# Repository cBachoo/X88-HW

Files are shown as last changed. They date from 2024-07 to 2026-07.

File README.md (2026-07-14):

# X88H - Hybrid USB/JST





## License

This work is licensed under a [Creative Commons Attribution-ShareAlike 4.0 International License](https://creativecommons.org/licenses/by-sa/4.0/).

You are free to produce, modify, manufacture, and distribute this design, including for commercial purposes, provided you give appropriate credit and license any derivative works under the same terms.

Questions? Contact Bachoo (`bachoobusiness[at]gmail.com`).

[][cc-by-sa]

[cc-by-sa]: http://creativecommons.org/licenses/by-sa/4.0/
[cc-by-sa-image]: https://licensebuttons.net/l/by-sa/4.0/88x31.png
[cc-by-sa-shield]: https://img.shields.io/badge/License-CC%20BY--SA%204.0-lightgrey.svg

## Changelog

- 17 Aug 2024
    - Rotated JST connector so it's facing the alphas

## Design Files / Libraries

The files were designed with [KiCAD 8.0.4](https://www.kicad.org/).

The [marbastlib](https://github.com/ebastler/marbastlib) MX switch symbol/footprint library is used for the project.

The 3D model for the PCB can be seen in the main folder under `X88H-3D-model.step`.

## Ordering from JLCPCB

1) Head to the [JLCPCB order page](https://cart.jlcpcb.com/quote).

2) Upload the `GERBER-X88H.zip` file in `jlcpcb/production_files/`.

3) Set the quantity of the PCBs you want made.

4) Set your desired PCB parameters. Here are some suggested parameters: (Everything else can be kept at their default)

- PCB Color: **Black**
- Surface Finish: **ENIG**
- Remove Order Number: **Yes**   

5) Enable the PCB Assembly option at the bottom, and set the following parameters:

- PCBA Type: **Standard**
- Assembly Side: **Both Sides**

6) Press `Confirm` at the bottom or `NEXT` on the right to get to the next page.

7) Click `NEXT` to get to the Bill of Materials tab.

8) Click `Add BOM File` and select the `BOM-X88H.csv` file in `jlcpcb/production_files/`.

9) Click `Add CPL File` and select the `CPL-X88H.csv` file in `jlcpcb/production_files/`. Click `Process BOM & CPL` to proceed.

10) You should be presented with a list of all the components and quantities needed. Double check there are no missing components. If there are, you will have to find substitute components for it. Click `NEXT` to proceed.

11) You should be presented with a view of the PCB and its components. Click `NEXT` to proceed.

12) You should see a breakdown of the price for the PCBs you want to order. Select `Keyboard - HS Code 847330` under `Office Appliance Accessories` for the Product Description.

13) Save to cart, and pay for it!

## Ordering from PCBWay

1) Head to the [PCBWay Quick Order page](https://www.pcbway.com/QuickOrderOnline.aspx)

2) Click the `Add Gerber file` button and add the `X88H.kicad_pcb.zip` file in the main folder. Don't worry about the broken preview.

3) Set the quantity of the PCBs you want made.

4) Set your desired PCB parameters. Here are some suggested parameters: (Everything else can be kept at their default)

- Solder mask: **Black**
- Surface finish: **Immersion gold (ENIG)**
- Remove product no.: **Yes (extra+$1.5)**

5) Enable the Assembly Service option at the bottom, and set the following parameters:

- Assembly side(s): **Both sides**
- Quantity: **as needed; same number as your PCBs?**
- Do you accept alternatives/substitutes made in China? **Yes**

6) Click Save to Cart. You will have to wait for your order to be reviewed before you can pay for it.

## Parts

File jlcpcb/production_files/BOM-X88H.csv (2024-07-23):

Comment | Designator | Footprint | LCSC
100nF | C10,C11,C2,C3,C7,C9 | C_0402_1005Metric | C1525
10uF | CR1 | C_0402_1005Metric | C15525
SM04B-SRSS-TB | J1 | JST_SH_SM04B-SRSS-TB_1x04-1MP_P1.00mm_Horizontal | C160404
USB_C_Receptacle_USB2.0_16P | USB1 | USB_C_Receptacle_HRO_TYPE-C-31-M-12 | C165948
4.7uF | C1,C8 | C_0402_1005Metric | C23733
100k | RR3 | R_0402_1005Metric | C25741
10k | RR2 | R_0402_1005Metric | C25744
33k | RR1 | R_0402_1005Metric | C25779
4k7 | R3 | R_0402_1005Metric | C25900
5k1 | R1,R2 | R_0402_1005Metric | C25905
PRTR5V0U2X | D1 | SOT-143 | C2827688
TS-1187A-B-A-B | SWR1 | SW_SPST_TL3342 | C318884
SK6812MINI-E | RGB1,RGB2 | LED_6028R | C524051
1uF | C4,C5,C6,CR2 | C_0402_1005Metric | C52923
XC6206P332MR | U1 | SOT-23 | C5446
500mA | F1 | Fuse_1206_3216Metric_Pad1.42x1.75mm_HandSolder | C69688
1N4148W | D10,D11,D12,D13,D14,D15,D16,D17,D18,D19,D2,D20,D21,D22,D23,D24,D25,D26,D27,D28,D29,D3,D30,D31,D32,D33,D34,D35,D36,D37,D38,D39,D4,D40,D41,D42,D43,D44,D45,D46,D47,D48,D49,D5,D50,D51,D52,D53,D54,D55,D56,D57,D58,D59,D6,D60,D61,D62,D63,D64,D65,D66,D67,D68,D69,D7,D70,D71,D72,D73,D74,D75,D76,D77,D78,D79,D8,D80,D81,D82,D83,D84,D85,D86,D87,D88,D89,D9,D90,D91,D92 | D_SOD-123 | C81598
STM32F072CBT6 | U2 | LQFP-48_7x7mm_P0.5mm | C81720
2N7002 | QR1 | SOT-23 | C8545

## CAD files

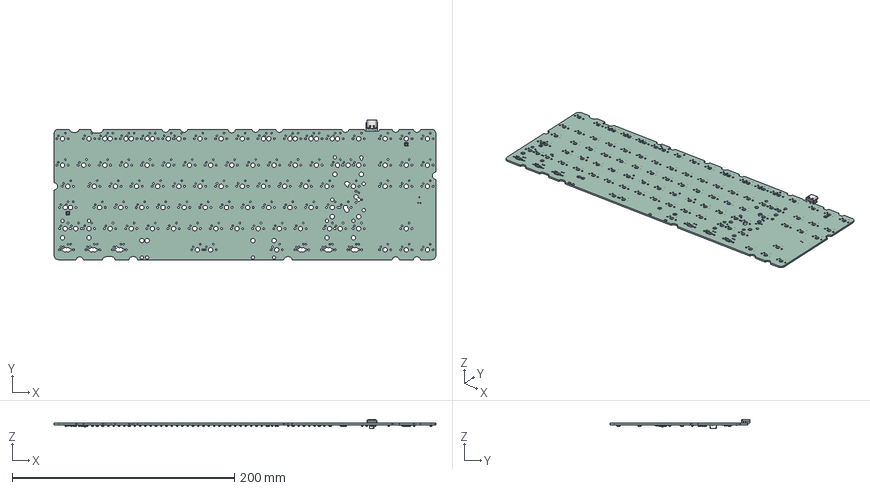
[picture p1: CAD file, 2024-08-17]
X88H-3D-model.step
344.0 x 125.6 x 7.86 mm
CON_TYPE-C-31-M-12 v3
D_SOD_123 x 91
LQFP_48_7x7mm_P05mm
R_0402_1005Metric x 6
C_0402_1005Metric x 13
SW_SPST_TL3342
LED_SK6812MINI-E v2 x 2
SOT_23 x 2
CON_SM04B-SRSS-TB v2
SOT_143
Fuse_1206_3216Metric
X88H_PCB

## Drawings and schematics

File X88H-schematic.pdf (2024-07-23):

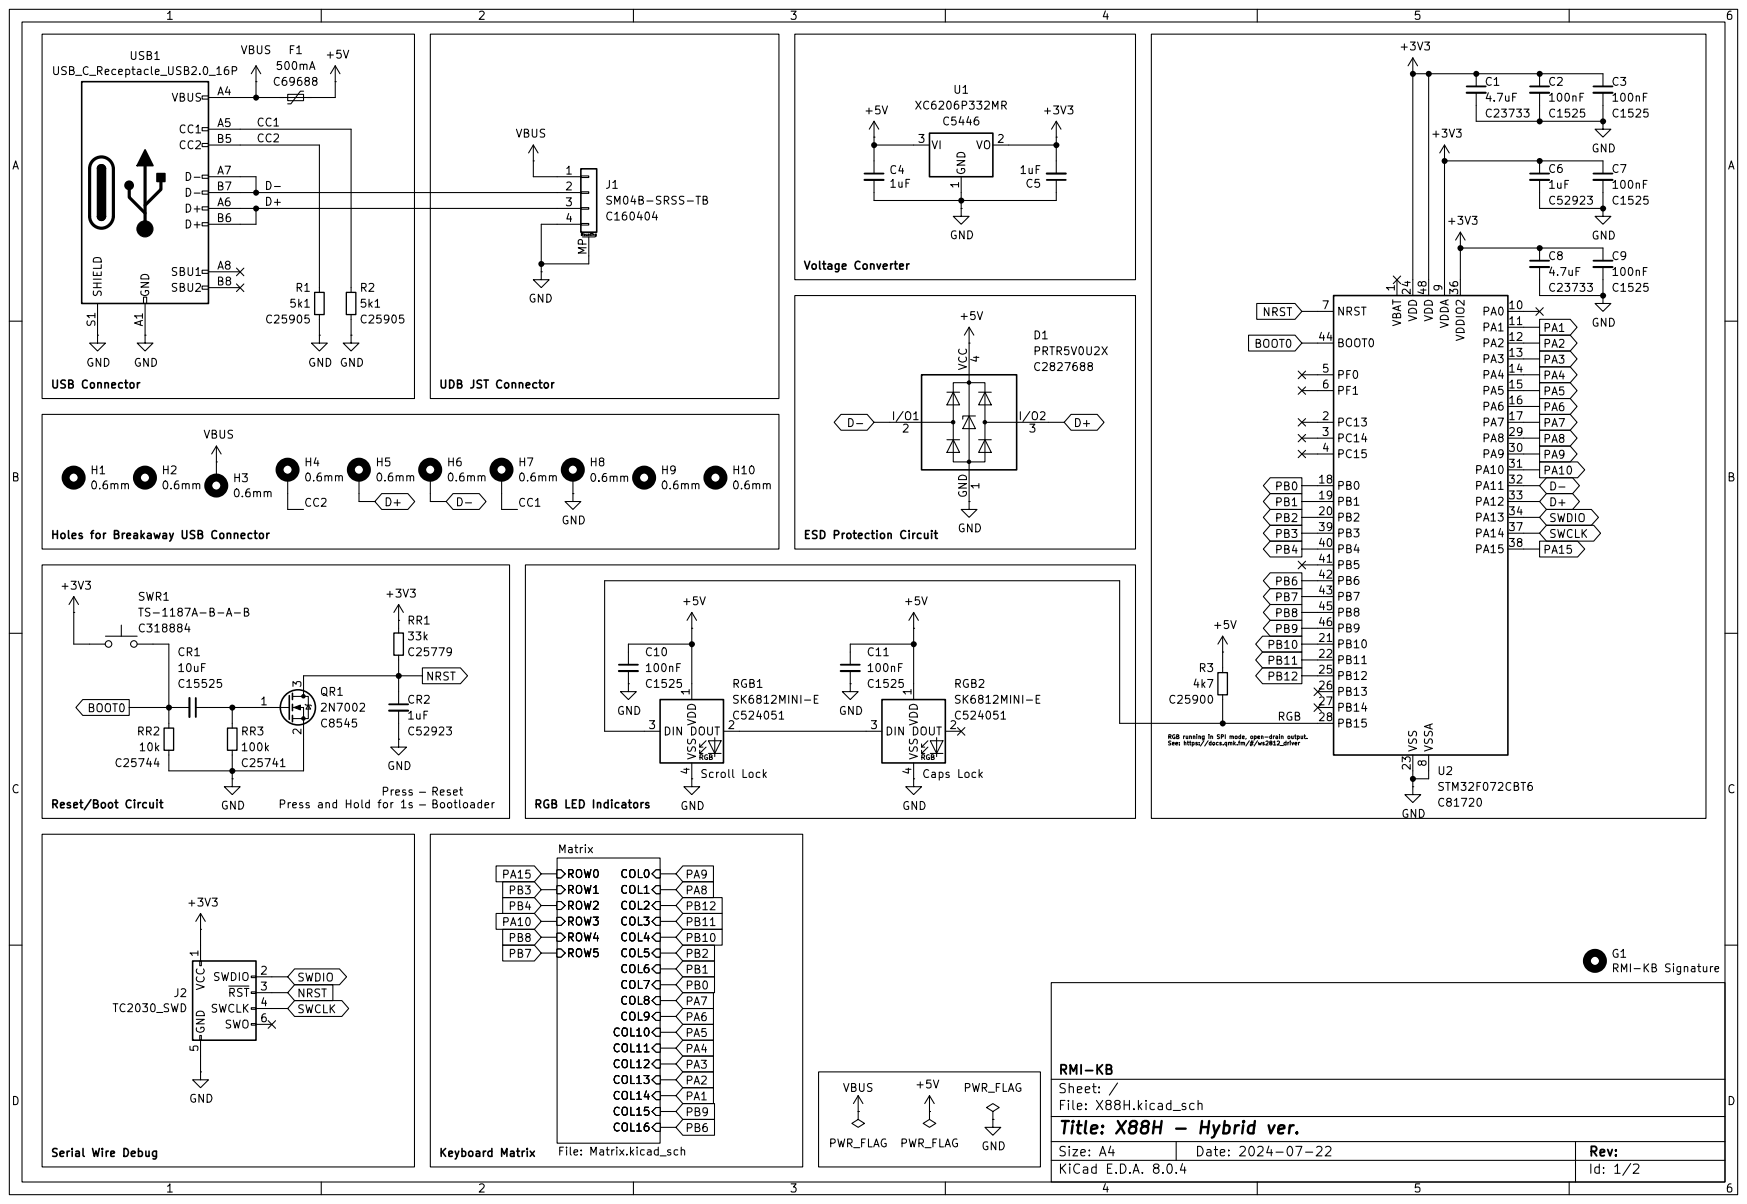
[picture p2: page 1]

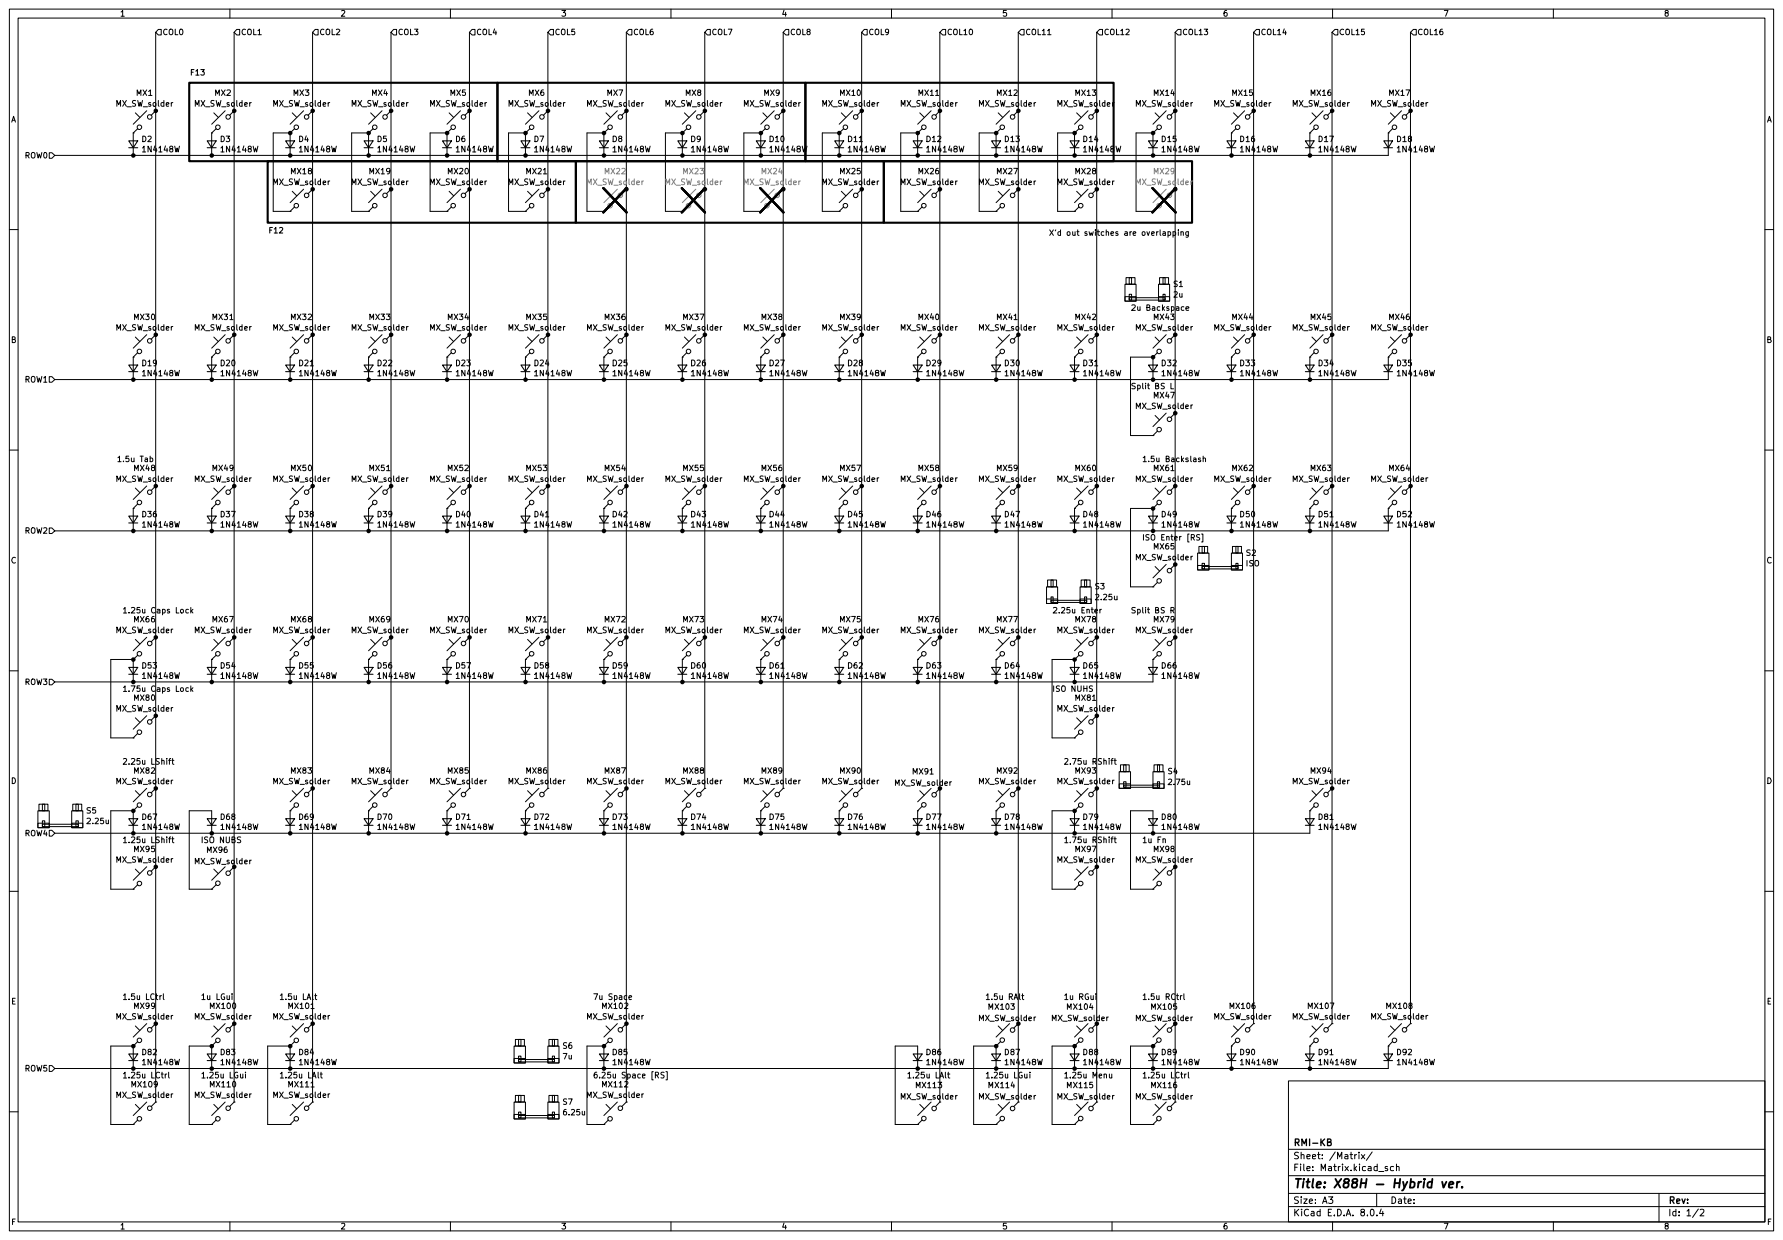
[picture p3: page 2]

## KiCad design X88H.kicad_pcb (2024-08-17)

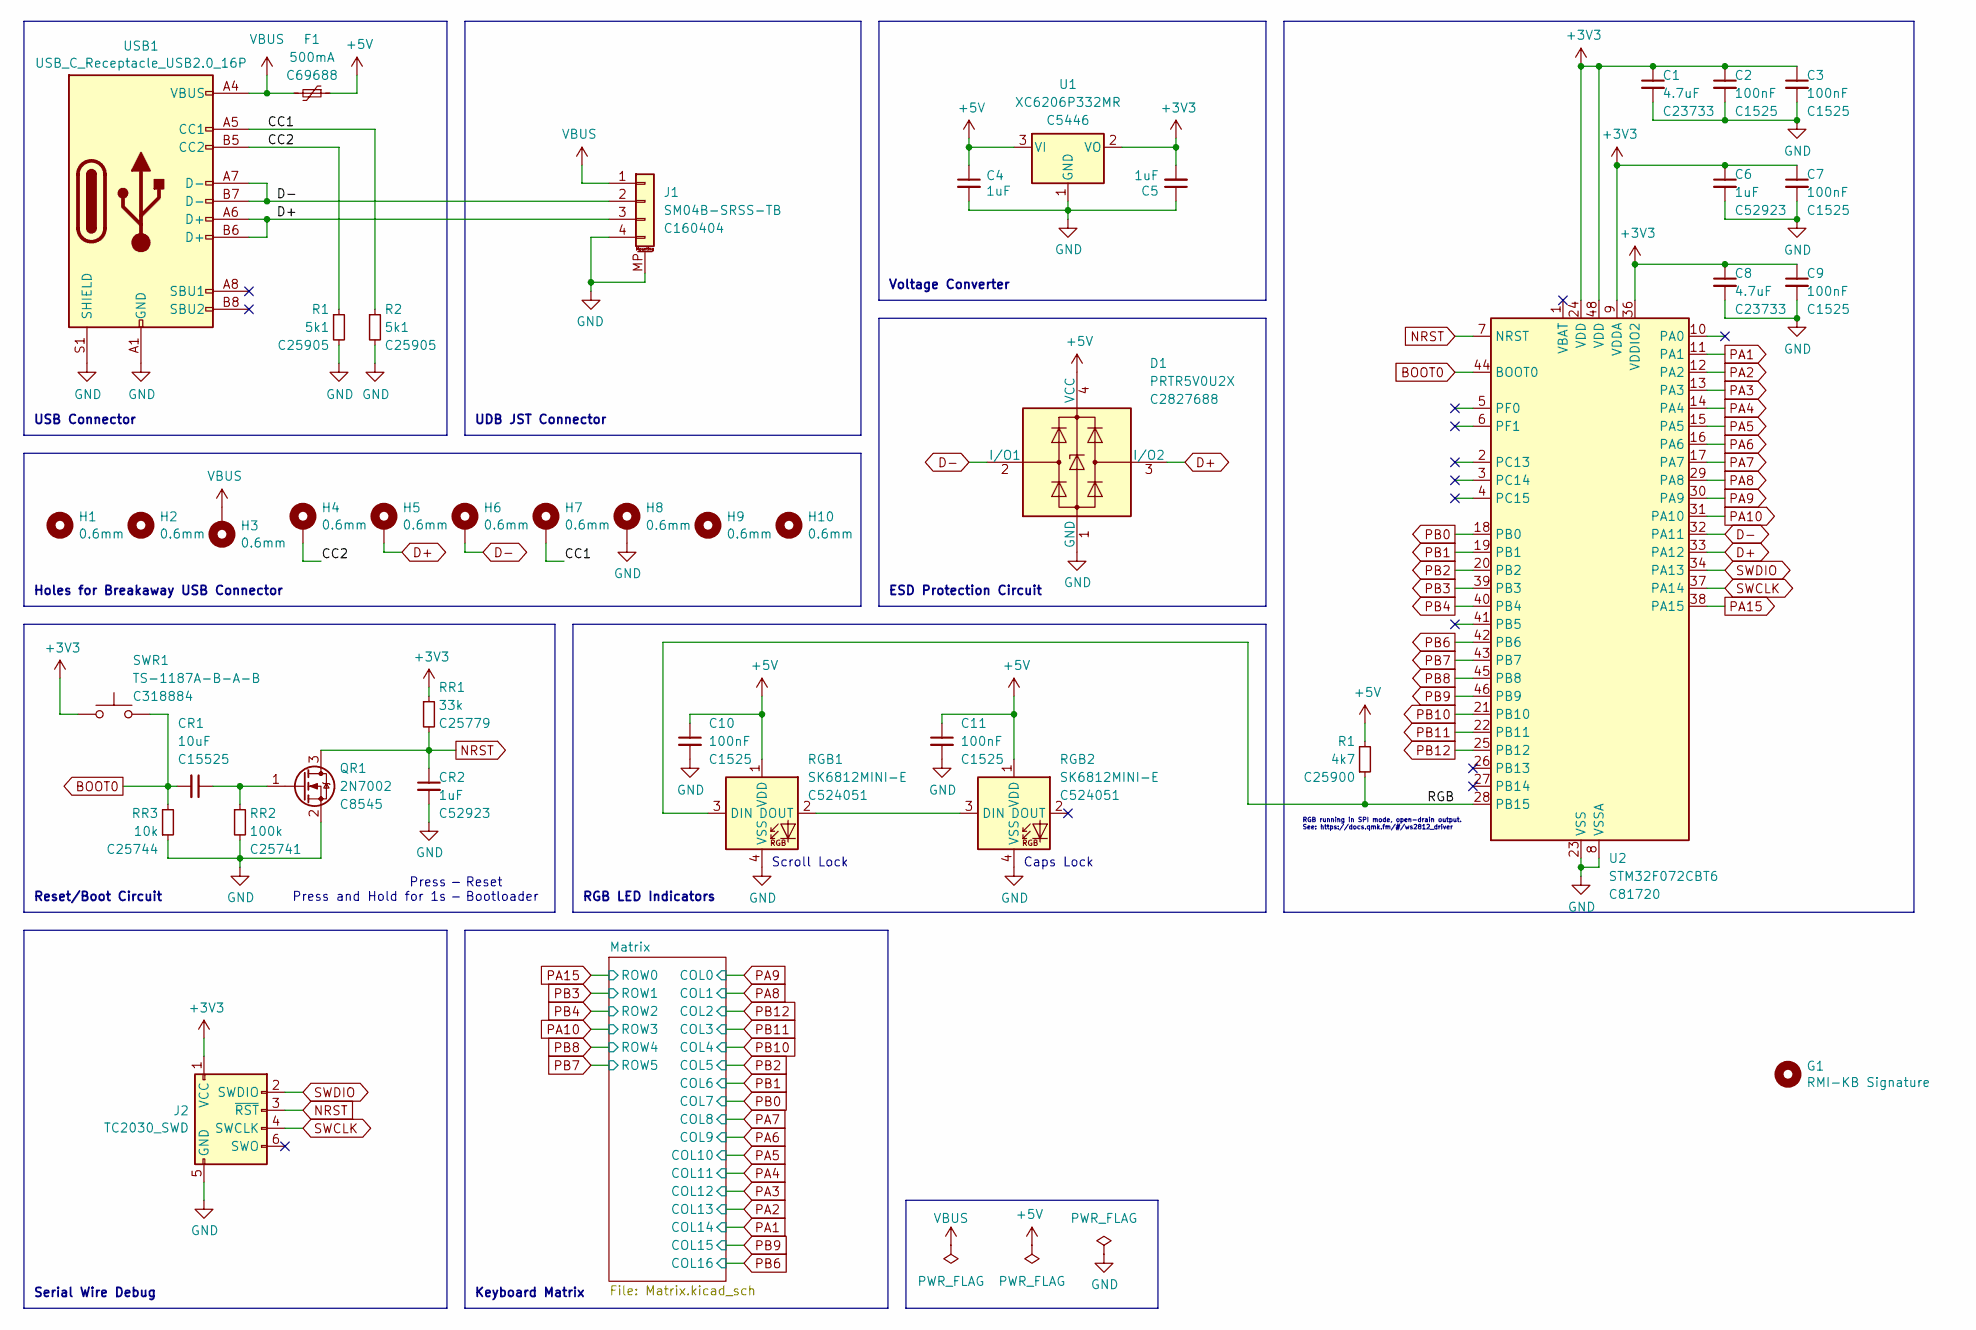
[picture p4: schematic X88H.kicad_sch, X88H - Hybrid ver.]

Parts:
C1, C8: 4.7uF; C_0402_1005Metric; MPN CL05A475MP5NRNC; LCSC C23733
C2, C3, C7, C9, C10, C11: 100nF; C_0402_1005Metric; MPN CL05B104KO5NNNC; LCSC C1525
C4, C5, C6: 1uF; C_0402_1005Metric; MPN CL05A105KA5NQNC; LCSC C52923
CR1: 10uF; C_0402_1005Metric; MPN CL05A106MQ5NUNC; LCSC C15525
CR2: 1uF; C_0402_1005Metric; MPN CL05A105KA5NQNC; LCSC C52923
D1: PRTR5V0U2X; SOT-143; MPN PRTR5V0U2X; LCSC C2827688
F1: 500mA; Fuse_1206_3216Metric_Pad1.42x1.75mm_HandSolder; MPN nSMD050; LCSC C69688
G1: RMI-KB Signature; Signature
H1, H2, H9, H10: 0.6mm; Hole_0.6mm
H3, H4, H5, H6, H7, H8: 0.6mm; Hole_0.6mm_Pad
J1: SM04B-SRSS-TB; JST_SH_SM04B-SRSS-TB_1x04-1MP_P1.00mm_Horizontal; MPN SM04B-SRSS-TB(LF)(SN); LCSC C160404
J2: TC2030_SWD; CON_TC2030_outlined
QR1: 2N7002; SOT-23; MPN 2N7002; LCSC C8545
R1, R2: 5k1; R_0402_1005Metric; MPN 0402WGF5101TCE; LCSC C25905
RGB1, RGB2: SK6812MINI-E; LED_6028R; MPN SK6812MINI-E; LCSC C524051
RR1: 33k; R_0402_1005Metric; MPN 0402WGF3302TCE; LCSC C25779
RR2: 100k; R_0402_1005Metric; MPN 0402WGF1003TCE; LCSC C25741
RR3: 10k; R_0402_1005Metric; MPN 0402WGF1002TCE; LCSC C25744
SWR1: TS-1187A-B-A-B; SW_SPST_TL3342; MPN TS-1187A-B-A-B; LCSC C318884
U1: XC6206P332MR; SOT-23; MPN XC6206P332MR-G; LCSC C5446
U2: STM32F072CBT6; LQFP-48_7x7mm_P0.5mm; MPN STM32F072CBT6; LCSC C81720
USB1: USB_C_Receptacle_USB2.0_16P; USB_C_Receptacle_HRO_TYPE-C-31-M-12; MPN TYPE-C-31-M-12; LCSC C165948

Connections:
+3V3: C1.1, C2.1, C3.1, C5.2, C6.1, C7.1, C8.1, C9.1, J2.1 (VCC), RR1.1, SWR1.1, U1.2 (VO), U2.9 (VDDA), U2.24 (VDD), U2.36 (VDDIO2), U2.48 (VDD)
/CC1: H7.1, R2.1, USB1.A5 (CC1)
D+: D1.3 (I/O2), H5.1, J1.3, U2.33 (PA12), USB1.A6 (D+), USB1.B6 (D+)
D-: D1.2 (I/O1), H6.1, J1.2, U2.32 (PA11), USB1.A7 (D-), USB1.B7 (D-)
NRST: CR2.1, J2.3 (~RST), QR1.3 (D), RR1.2, U2.7 (NRST)
unnamed: RGB1.2 (DOUT), RGB2.3 (DIN)
PA1: U2.11 (PA1); also elsewhere on the board
PA2: U2.12 (PA2); also elsewhere on the board
PA3: U2.13 (PA3); also elsewhere on the board
PA4: U2.14 (PA4); also elsewhere on the board
PA5: U2.15 (PA5); also elsewhere on the board
PA6: U2.16 (PA6); also elsewhere on the board
PA7: U2.17 (PA7); also elsewhere on the board
PA8: U2.29 (PA8); also elsewhere on the board
PA9: U2.30 (PA9); also elsewhere on the board
PA10: U2.31 (PA10); also elsewhere on the board
PA15: U2.38 (PA15); also elsewhere on the board
PB0: U2.18 (PB0); also elsewhere on the board
PB1: U2.19 (PB1); also elsewhere on the board
PB2: U2.20 (PB2); also elsewhere on the board
PB3: U2.39 (PB3); also elsewhere on the board
PB4: U2.40 (PB4); also elsewhere on the board
PB6: U2.42 (PB6); also elsewhere on the board
PB7: U2.43 (PB7); also elsewhere on the board
PB8: U2.45 (PB8); also elsewhere on the board
PB9: U2.46 (PB9); also elsewhere on the board
PB10: U2.21 (PB10); also elsewhere on the board
PB11: U2.22 (PB11); also elsewhere on the board
PB12: U2.25 (PB12); also elsewhere on the board
SWCLK: J2.4 (SWCLK), U2.37 (PA14)
SWDIO: J2.2 (SWDIO), U2.34 (PA13)
VBUS: F1.2, H3.1, J1.1, USB1.A4 (VBUS), USB1.A9 (VBUS), USB1.B4 (VBUS), USB1.B9 (VBUS)

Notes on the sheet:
Holes for Breakaway USB Connector
Reset Bootloader
ESD Protection Circuit
Caps Lock
RGB running in SPI mode, open-drain output. See: https://docs.qmk.fm/#/ws2812_driver
- -
UDB JST Connector
RGB LED Indicators
Voltage Converter
Press Press and Hold for 1s
Reset/Boot Circuit
Serial Wire Debug
Keyboard Matrix
USB Connector
Scroll Lock

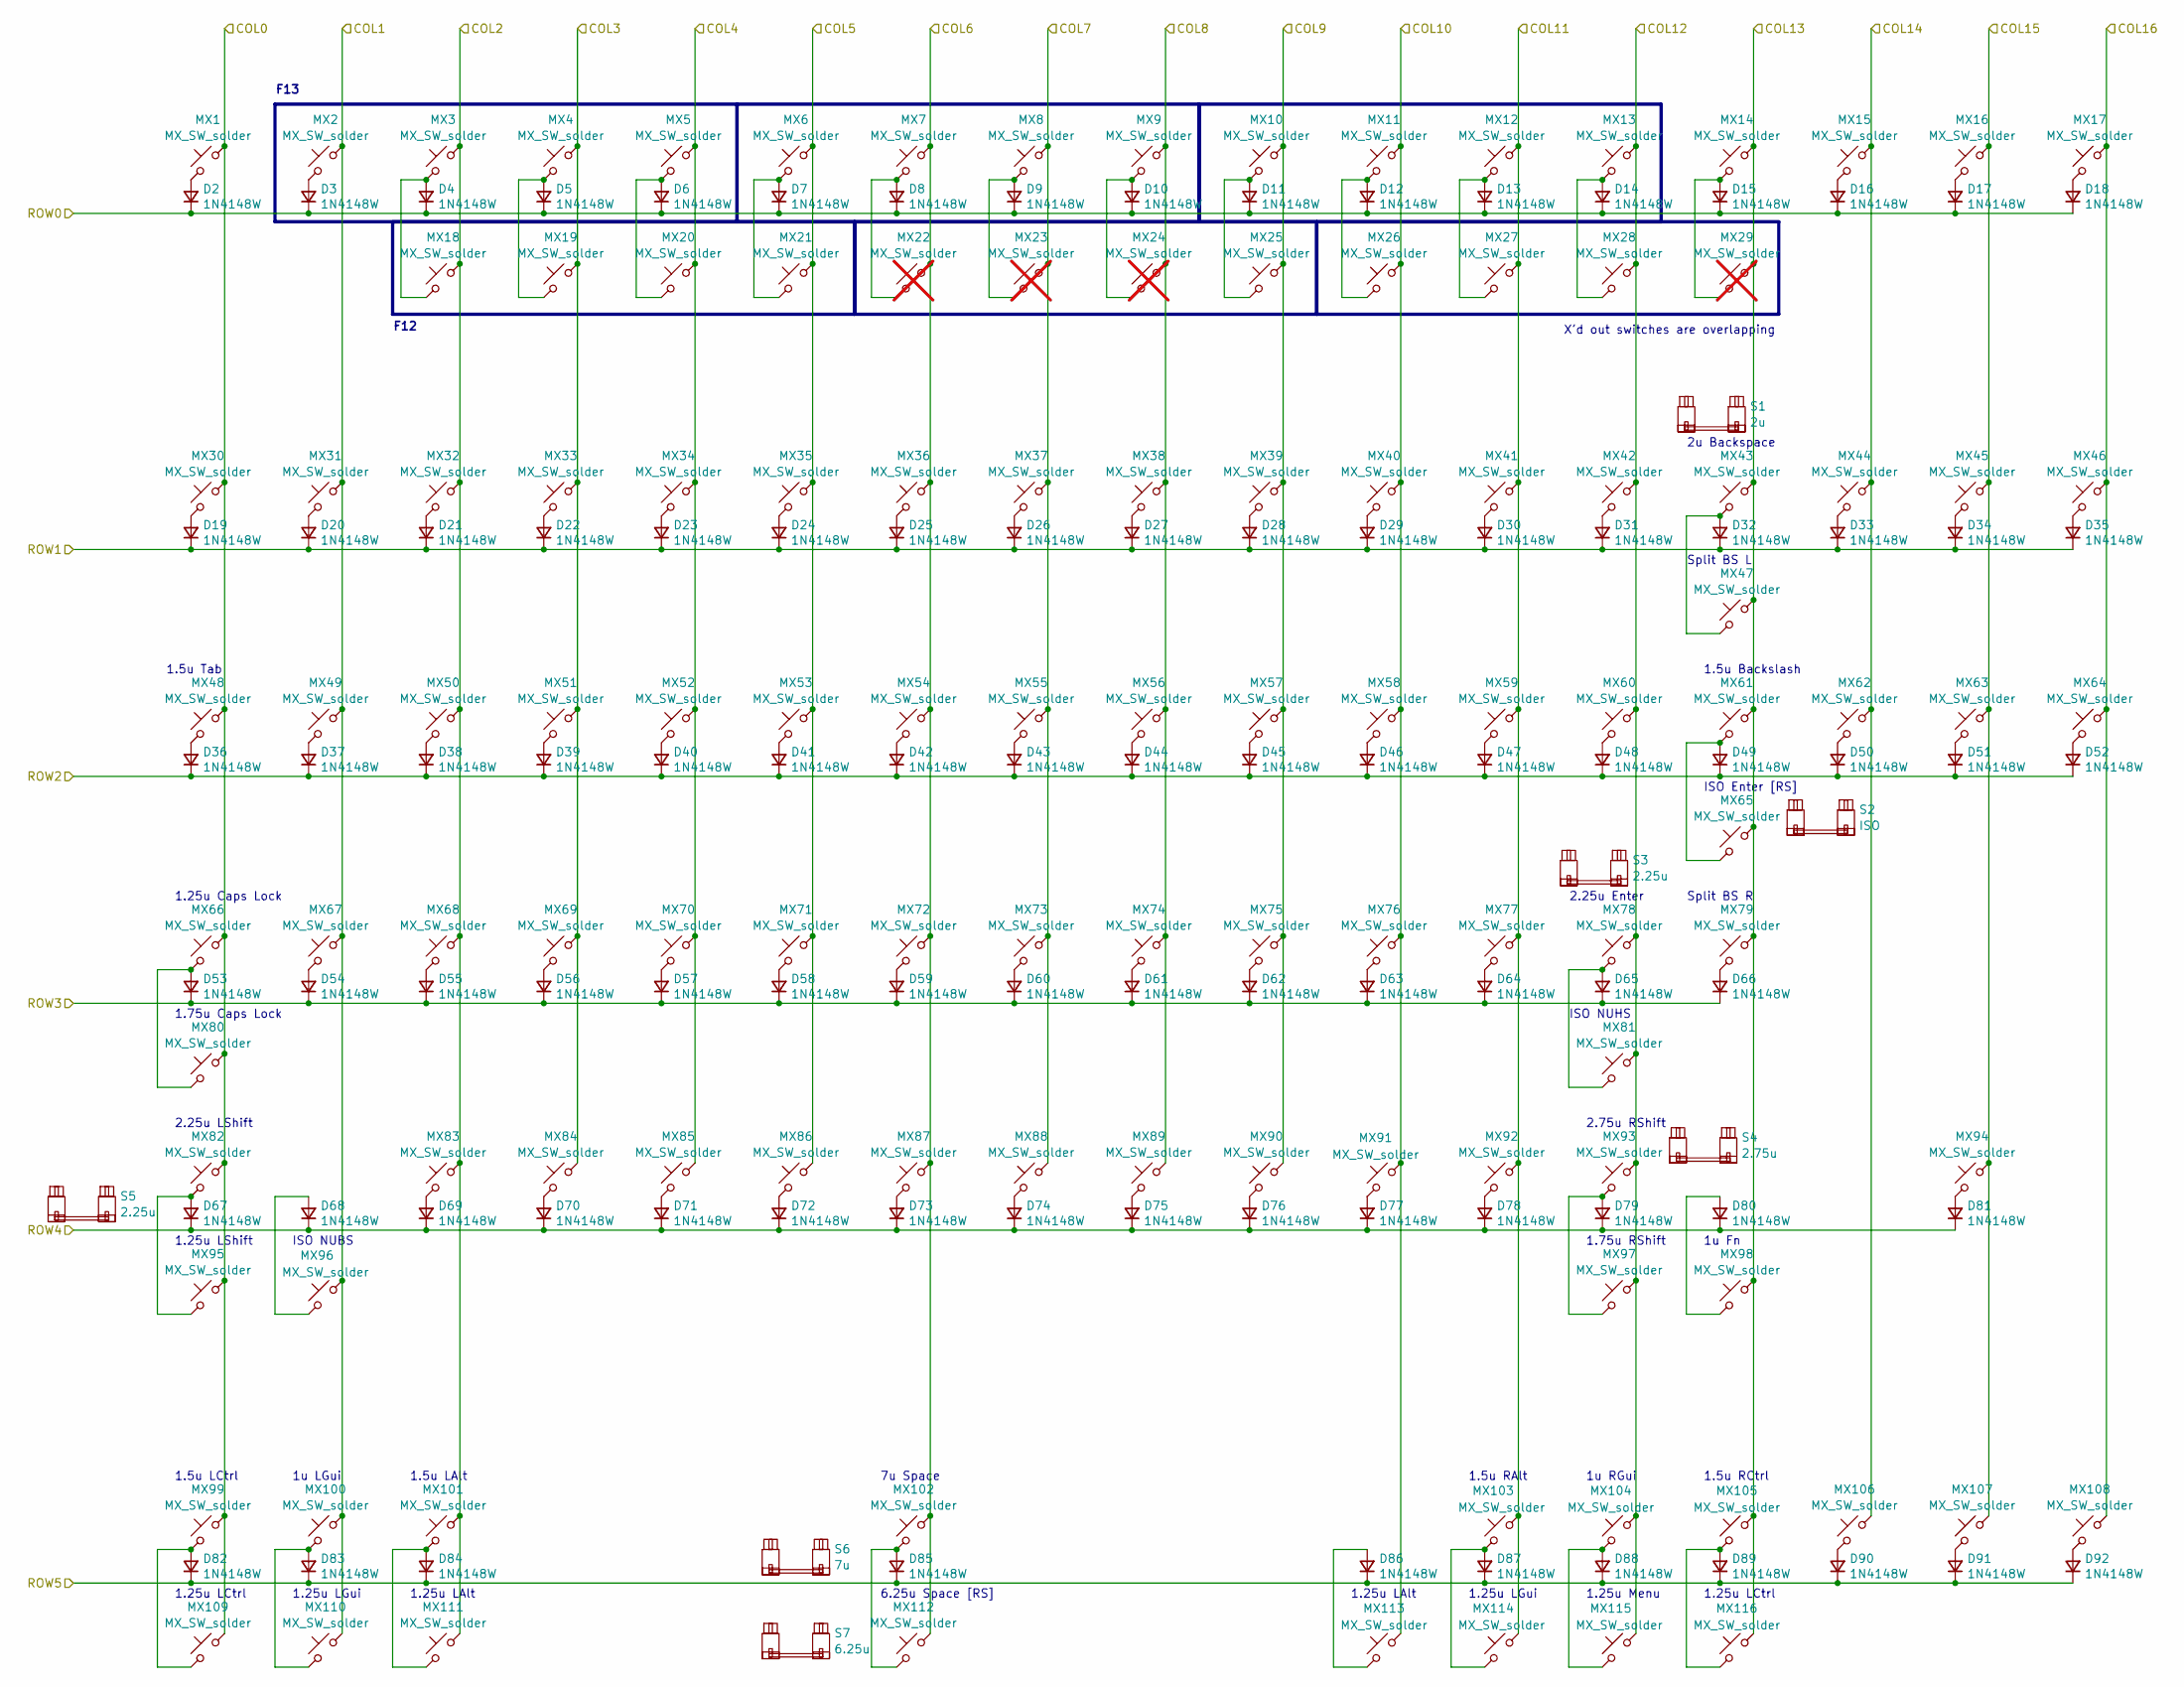
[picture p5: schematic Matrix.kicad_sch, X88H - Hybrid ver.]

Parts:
D2, D3, D4, D5, D6, D7, D8, D9, D10, D11, D12, D13, D14, D15, D16, D17, D18, D19, D20, D21, D22, D23, D24, D25, D26, D27, D28, D29, D30, D31, D32, D33, D34, D35, D36, D37, D38, D39, D40, D41, D42, D43, D44, D45, D46, D47, D48, D49, D50, D51, D52, D53, D54, D55, D56, D57, D58, D59, D60, D61, D62, D63, D64, D65, D66, D67, D68, D69, D70, D71, D72, D73, D74, D75, D76, D77, D78, D79, D80, D81, D82, D83, D84, D85, D86, D87, D88, D89, D90, D91, D92: 1N4148W; D_SOD-123; MPN 1N4148W; LCSC C81598
MX1, MX2, MX3, MX4, MX5, MX6, MX7, MX8, MX9, MX10, MX11, MX12, MX13, MX14, MX15, MX16, MX17, MX18, MX19, MX20, MX21, MX25, MX26, MX27, MX28, MX30, MX31, MX32, MX33, MX34, MX35, MX36, MX37, MX38, MX39, MX40, MX41, MX42, MX43, MX44, MX45, MX46, MX47, MX49, MX50, MX51, MX52, MX53, MX54, MX55, MX56, MX57, MX58, MX59, MX60, MX62, MX63, MX64, MX65, MX67, MX68, MX69, MX70, MX71, MX72, MX73, MX74, MX75, MX76, MX77, MX78, MX79, MX81, MX82, MX83, MX84, MX85, MX86, MX87, MX88, MX89, MX90, MX91, MX92, MX93, MX94, MX96, MX98, MX100, MX102, MX104, MX106, MX107, MX108, MX112: MX_SW_solder; SW_MX_1u
MX22, MX23, MX24, MX29: MX_SW_solder; SW_MX_1u; not fitted
MX48, MX61, MX99, MX101, MX103, MX105: MX_SW_solder; SW_MX_1.5u
MX66: MX_SW_solder; SW_MX_1.75u_STP_1.25
MX80, MX97: MX_SW_solder; SW_MX_1.75u
MX95, MX109, MX110, MX111, MX113, MX114, MX115, MX116: MX_SW_solder; SW_MX_1.25u
S1: 2u; STAB_MX_2u
S2: ISO; STAB_MX_ISO-ROT
S3, S5: 2.25u; STAB_MX_2.25u
S4: 2.75u; STAB_MX_2.75u
S6: 7u; STAB_MX_7u
S7: 6.25u; STAB_MX_6.25u

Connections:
unnamed: D2.2 (A), MX1.2
unnamed: D3.2 (A), MX2.2
unnamed: D4.2 (A), MX3.2, MX18.2
unnamed: D5.2 (A), MX4.2, MX19.2
unnamed: D6.2 (A), MX5.2, MX20.2
unnamed: D7.2 (A), MX6.2, MX21.2
unnamed: D8.2 (A), MX7.2, MX22.2
unnamed: D9.2 (A), MX8.2, MX23.2
unnamed: D10.2 (A), MX9.2, MX24.2
unnamed: D11.2 (A), MX10.2, MX25.2
unnamed: D12.2 (A), MX11.2, MX26.2
unnamed: D13.2 (A), MX12.2, MX27.2
unnamed: D14.2 (A), MX13.2, MX28.2
unnamed: D15.2 (A), MX14.2, MX29.2
unnamed: D16.2 (A), MX15.2
unnamed: D17.2 (A), MX16.2
unnamed: D18.2 (A), MX17.2
unnamed: D19.2 (A), MX30.2
unnamed: D20.2 (A), MX31.2
unnamed: D21.2 (A), MX32.2
unnamed: D22.2 (A), MX33.2
unnamed: D23.2 (A), MX34.2
unnamed: D24.2 (A), MX35.2
unnamed: D25.2 (A), MX36.2
unnamed: D26.2 (A), MX37.2
unnamed: D27.2 (A), MX38.2
unnamed: D28.2 (A), MX39.2
unnamed: D29.2 (A), MX40.2
unnamed: D30.2 (A), MX41.2
unnamed: D31.2 (A), MX42.2
unnamed: D32.2 (A), MX43.2, MX47.2
unnamed: D33.2 (A), MX44.2
unnamed: D34.2 (A), MX45.2
unnamed: D35.2 (A), MX46.2
unnamed: D36.2 (A), MX48.2
unnamed: D37.2 (A), MX49.2
unnamed: D38.2 (A), MX50.2
unnamed: D39.2 (A), MX51.2
unnamed: D40.2 (A), MX52.2
unnamed: D41.2 (A), MX53.2
unnamed: D42.2 (A), MX54.2
unnamed: D43.2 (A), MX55.2
unnamed: D44.2 (A), MX56.2
unnamed: D45.2 (A), MX57.2
unnamed: D46.2 (A), MX58.2
unnamed: D47.2 (A), MX59.2
unnamed: D48.2 (A), MX60.2
unnamed: D49.2 (A), MX61.2, MX65.2
unnamed: D50.2 (A), MX62.2
unnamed: D51.2 (A), MX63.2
unnamed: D52.2 (A), MX64.2
unnamed: D53.2 (A), MX66.2, MX80.2
unnamed: D54.2 (A), MX67.2
unnamed: D55.2 (A), MX68.2
unnamed: D56.2 (A), MX69.2
unnamed: D57.2 (A), MX70.2
unnamed: D58.2 (A), MX71.2
unnamed: D59.2 (A), MX72.2
unnamed: D60.2 (A), MX73.2
unnamed: D61.2 (A), MX74.2
unnamed: D62.2 (A), MX75.2
unnamed: D63.2 (A), MX76.2
unnamed: D64.2 (A), MX77.2
unnamed: D65.2 (A), MX78.2, MX81.2
unnamed: D66.2 (A), MX79.2
unnamed: D67.2 (A), MX82.2, MX95.2
unnamed: D68.2 (A), MX96.1
unnamed: D69.2 (A), MX83.2
unnamed: D70.2 (A), MX84.2
unnamed: D71.2 (A), MX85.2
unnamed: D72.2 (A), MX86.2
unnamed: D73.2 (A), MX87.2
unnamed: D74.2 (A), MX88.2
unnamed: D75.2 (A), MX89.2
unnamed: D76.2 (A), MX90.2
unnamed: D77.2 (A), MX91.1
unnamed: D78.2 (A), MX92.2
unnamed: D79.2 (A), MX93.2, MX97.2
unnamed: D80.2 (A), MX98.2
unnamed: D81.2 (A), MX94.2
unnamed: D82.2 (A), MX99.2, MX109.2
unnamed: D83.2 (A), MX100.2, MX110.2
unnamed: D84.2 (A), MX101.2, MX111.2
unnamed: D85.2 (A), MX102.2, MX112.2
unnamed: D86.2 (A), MX113.1
unnamed: D87.2 (A), MX103.1, MX114.1
unnamed: D88.2 (A), MX104.1, MX115.1
unnamed: D89.2 (A), MX105.1, MX116.1
unnamed: D90.2 (A), MX106.2
unnamed: D91.2 (A), MX107.2
unnamed: D92.2 (A), MX108.2
PA1: MX15.1, MX44.1, MX62.1, MX106.1; also elsewhere on the board
PA2: MX14.1, MX29.1, MX43.1, MX47.1, MX61.1, MX65.1, MX79.1, MX98.1, MX105.2, MX116.2; also elsewhere on the board
PA3: MX13.1, MX28.1, MX42.1, MX60.1, MX78.1, MX81.1, MX93.1, MX97.1, MX104.2, MX115.2; also elsewhere on the board
PA4: MX12.1, MX27.1, MX41.1, MX59.1, MX77.1, MX92.1, MX103.2, MX114.2; also elsewhere on the board
PA5: MX11.1, MX26.1, MX40.1, MX58.1, MX76.1, MX91.2, MX113.2; also elsewhere on the board
PA6: MX10.1, MX25.1, MX39.1, MX57.1, MX75.1, MX90.1; also elsewhere on the board
PA7: MX9.1, MX24.1, MX38.1, MX56.1, MX74.1, MX89.1; also elsewhere on the board
PA8: MX2.1, MX31.1, MX49.1, MX67.1, MX96.2, MX100.1, MX110.1; also elsewhere on the board
PA9: MX1.1, MX30.1, MX48.1, MX66.1, MX80.1, MX82.1, MX95.1, MX99.1, MX109.1; also elsewhere on the board
PA10: D53.1 (K), D54.1 (K), D55.1 (K), D56.1 (K), D57.1 (K), D58.1 (K), D59.1 (K), D60.1 (K), D61.1 (K), D62.1 (K), D63.1 (K), D64.1 (K), D65.1 (K), D66.1 (K); also elsewhere on the board
PA15: D2.1 (K), D3.1 (K), D4.1 (K), D5.1 (K), D6.1 (K), D7.1 (K), D8.1 (K), D9.1 (K), D10.1 (K), D11.1 (K), D12.1 (K), D13.1 (K), D14.1 (K), D15.1 (K), D16.1 (K), D17.1 (K), D18.1 (K); also elsewhere on the board
PB0: MX8.1, MX23.1, MX37.1, MX55.1, MX73.1, MX88.1; also elsewhere on the board
PB1: MX7.1, MX22.1, MX36.1, MX54.1, MX72.1, MX87.1, MX102.1, MX112.1; also elsewhere on the board
PB2: MX6.1, MX21.1, MX35.1, MX53.1, MX71.1, MX86.1; also elsewhere on the board
PB3: D19.1 (K), D20.1 (K), D21.1 (K), D22.1 (K), D23.1 (K), D24.1 (K), D25.1 (K), D26.1 (K), D27.1 (K), D28.1 (K), D29.1 (K), D30.1 (K), D31.1 (K), D32.1 (K), D33.1 (K), D34.1 (K), D35.1 (K); also elsewhere on the board
PB4: D36.1 (K), D37.1 (K), D38.1 (K), D39.1 (K), D40.1 (K), D41.1 (K), D42.1 (K), D43.1 (K), D44.1 (K), D45.1 (K), D46.1 (K), D47.1 (K), D48.1 (K), D49.1 (K), D50.1 (K), D51.1 (K), D52.1 (K); also elsewhere on the board
PB6: MX17.1, MX46.1, MX64.1, MX108.1; also elsewhere on the board
PB7: D82.1 (K), D83.1 (K), D84.1 (K), D85.1 (K), D86.1 (K), D87.1 (K), D88.1 (K), D89.1 (K), D90.1 (K), D91.1 (K), D92.1 (K); also elsewhere on the board
PB8: D67.1 (K), D68.1 (K), D69.1 (K), D70.1 (K), D71.1 (K), D72.1 (K), D73.1 (K), D74.1 (K), D75.1 (K), D76.1 (K), D77.1 (K), D78.1 (K), D79.1 (K), D80.1 (K), D81.1 (K); also elsewhere on the board
PB9: MX16.1, MX45.1, MX63.1, MX94.1, MX107.1; also elsewhere on the board
PB10: MX5.1, MX20.1, MX34.1, MX52.1, MX70.1, MX85.1; also elsewhere on the board
PB11: MX4.1, MX19.1, MX33.1, MX51.1, MX69.1, MX84.1; also elsewhere on the board
PB12: MX3.1, MX18.1, MX32.1, MX50.1, MX68.1, MX83.1, MX101.1, MX111.1; also elsewhere on the board

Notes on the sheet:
2u Backspace
1.5u LAlt
Split BS R
1u LGui
1.75u RShift
1.5u RAlt
ISO Enter [RS]
1.25u LCtrl
7u Space
1.75u Caps Lock
6.25u Space [RS]
F13
1.25u Caps Lock
ISO NUBS
1.5u Backslash
1.25u LGui
2.75u RShift
1u RGui
1.5u Tab
X'd out switches are overlapping
ISO NUHS
2.25u LShift
1.25u LAlt
1.25u LShift
1.25u Menu
1.5u LCtrl
1.5u RCtrl
2.25u Enter
Split BS L
1u Fn
F12

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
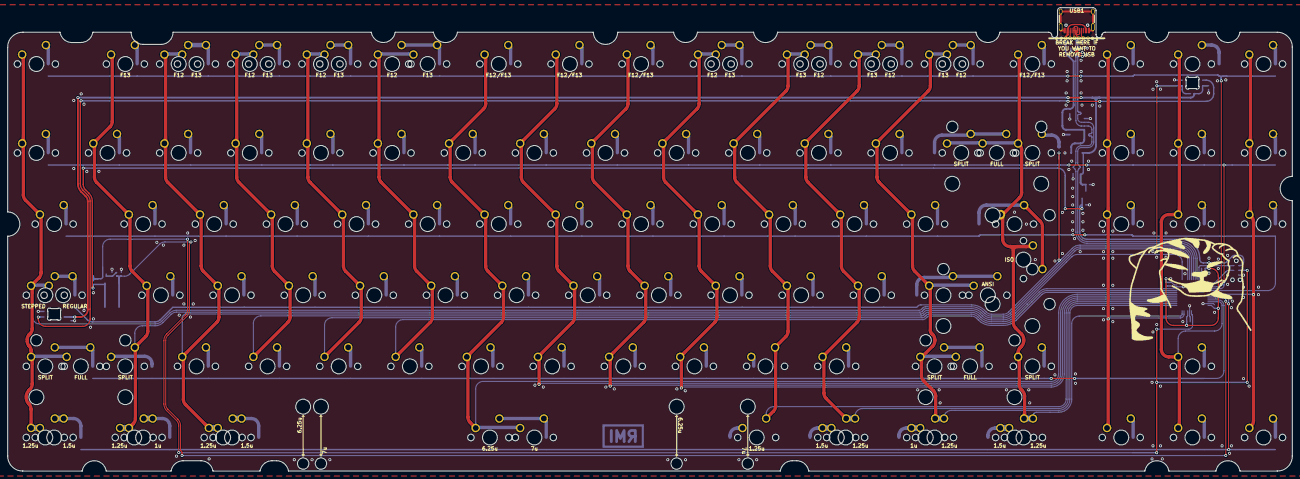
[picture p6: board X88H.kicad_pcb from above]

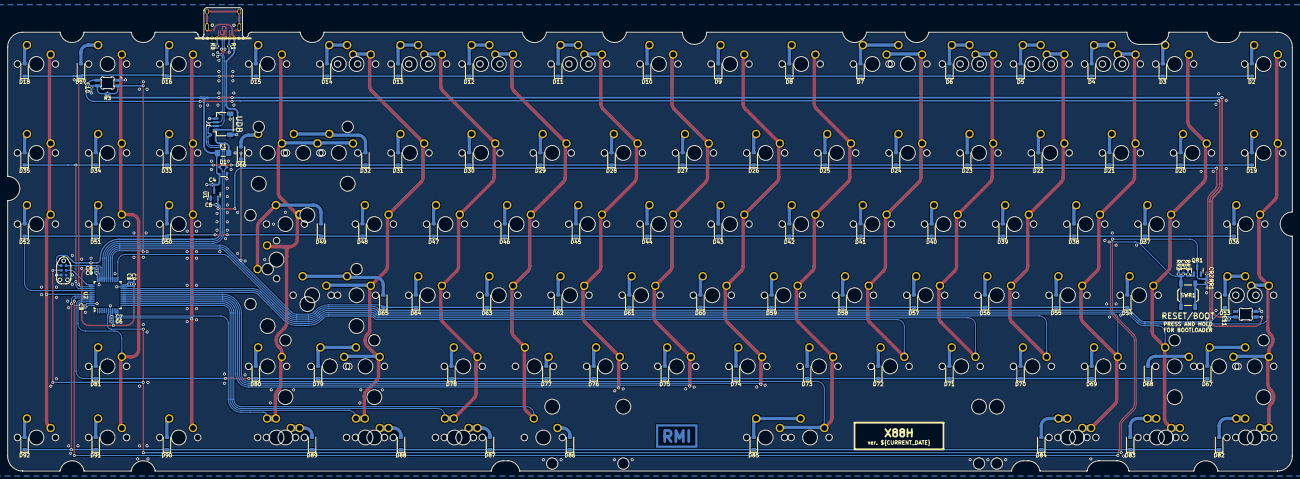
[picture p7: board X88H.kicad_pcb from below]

Board: 2 copper layers, 344.0 x 124.1 mm, 251 parts (121 on the bottom side), 129 nets.

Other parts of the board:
R3: 4k7; R_0402_1005Metric

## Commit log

2024-07-25 Generate PCB STEP file
2024-08-17 Rotate JST to face alphas
    [X88H-3D-model.step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]
